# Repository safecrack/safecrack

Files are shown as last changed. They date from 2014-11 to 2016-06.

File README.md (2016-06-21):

## Safecracker

An autodialer device built as part of the [Ruxcon](https://ruxcon.org.au/) 2014 presentation: [Safecracking on a Budget by Luke Jahnke & Jay Davis](http://2014.ruxcon.org.au/assets/2014/slides/rux-safe-cracking.pdf)

### Requirements

#### Hardware:

- 3D printed parts as per the files provided in the folder 3d_parts
- Arduino and compatible stepper motor shield, for this project the [Arduino Mega 2560](https://www.arduino.cc/en/Main/ArduinoBoardMega2560) and [Arduino Motor Shield](https://www.arduino.cc/en/Main/ArduinoMotorShieldR3) were used.
- [Stepper motor](https://littlebirdelectronics.com.au/products/stepper-motor-68-oz-in-400-steps-rev)
- [Hall Effect Sensor](http://www.freetronics.com.au/pages/hall-effect-magnetic-and-proximity-sensor-module-quickstart-guide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) and magnet for detecting if the lock is open. 
- [Mounting Hub](https://www.pololu.com/product/1203) for connecting the lock coupler to the stepper motor
- [Clamping Hub](https://littlebirdelectronics.com.au/products/clamping-hub-6mm-bore) for connecting chassis components.
- [Suction Cups](http://www.ggrglass.co.uk/suction-mounts/7kg-suction-mount-with-1-4-long-stud/) for mounting.

#### Software:

The code uploaded was used for the 2014 presentation but can be modified to be stand alone. It uses a python script to communicate over the usb/serial connection to the arduino to feed it combinations found on twitter. 

### License

See the [LICENSE](LICENSE) file for license rights and limitations.

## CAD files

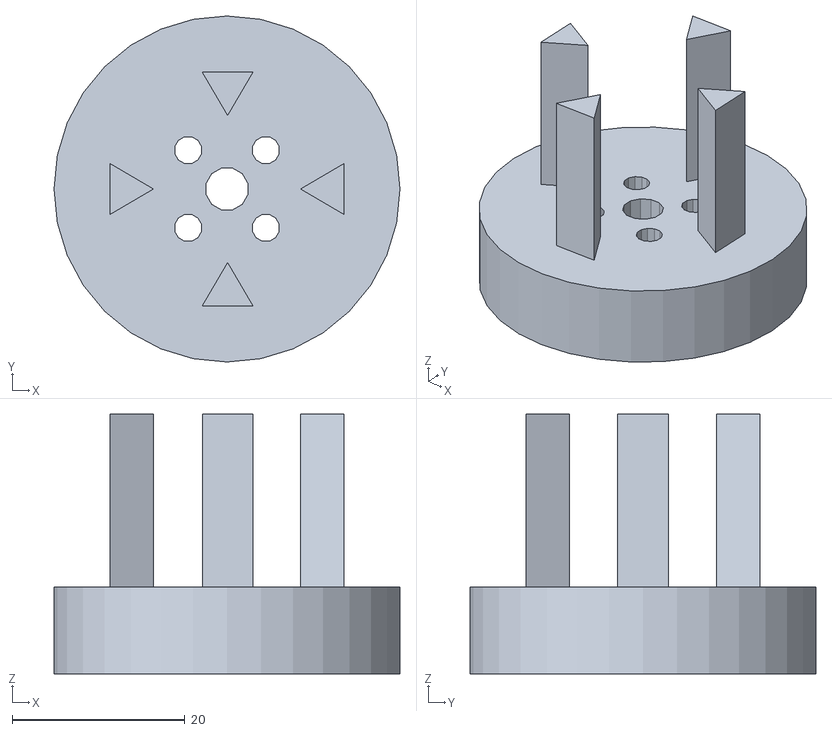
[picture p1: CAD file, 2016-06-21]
3d_parts/stl_files/master_lock_coupler.stl
40.0 x 40.0 x 30.0

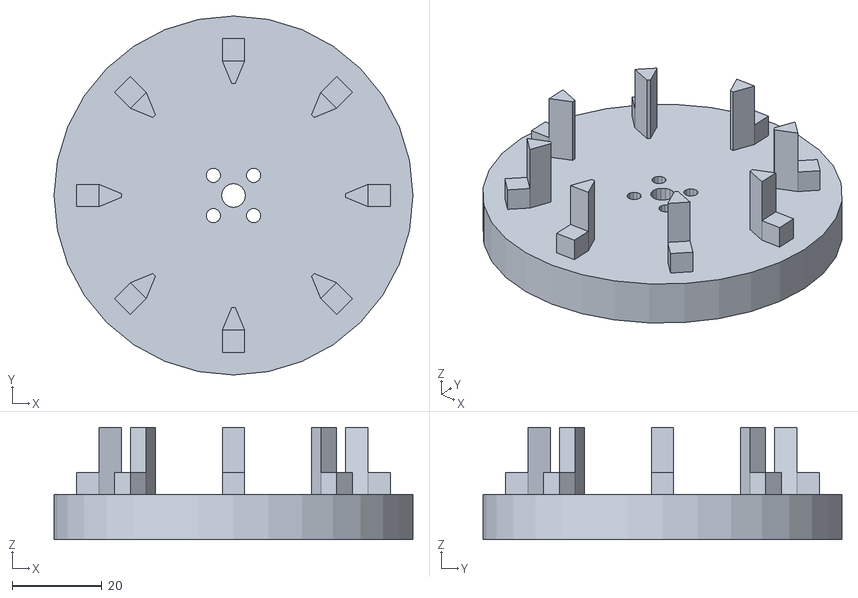
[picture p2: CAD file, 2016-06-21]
3d_parts/stl_files/la_guard_3330_coupler.stl
80.0 x 80.0 x 25.0

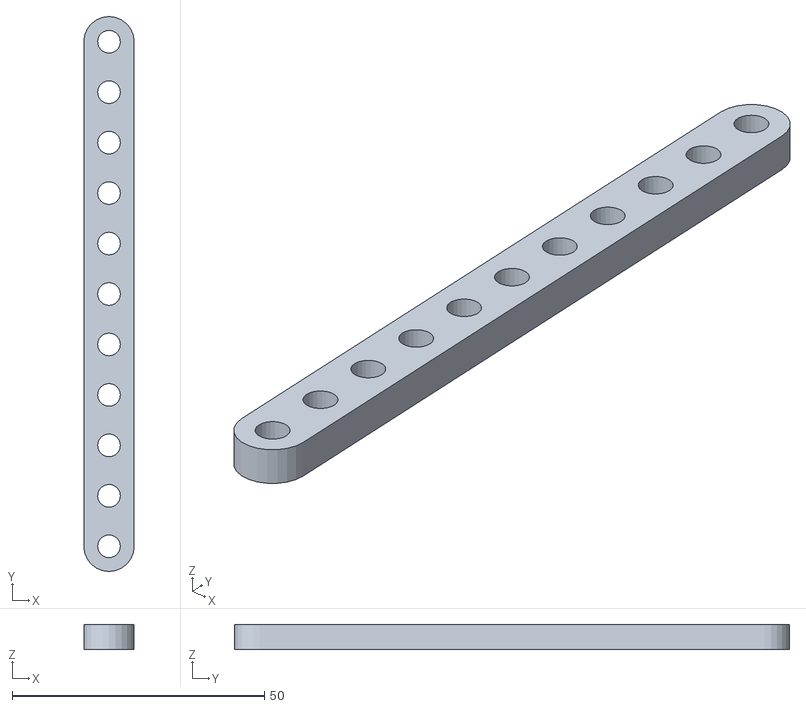
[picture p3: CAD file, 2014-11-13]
3d_parts/stl_files/sensor_arm_2.stl
10.0 x 110.0 x 5.00

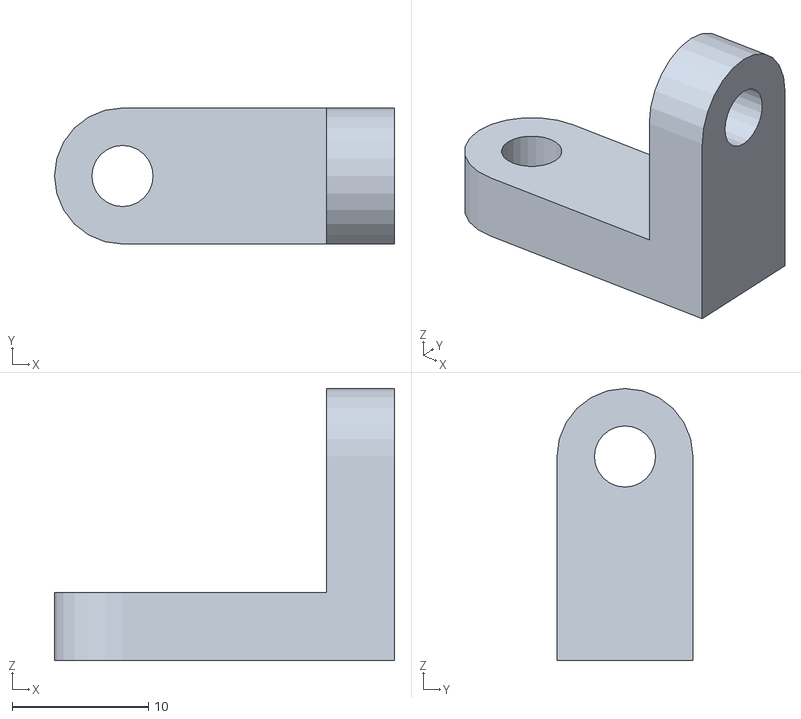
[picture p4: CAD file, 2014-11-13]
3d_parts/stl_files/sensor_arm_3.stl
25.0 x 10.00 x 20.0

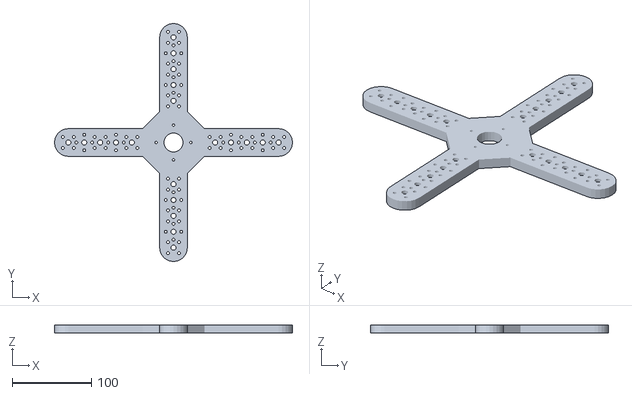
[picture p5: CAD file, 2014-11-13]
3d_parts/stl_files/topmount.stl
300.0 x 300.0 x 10.00

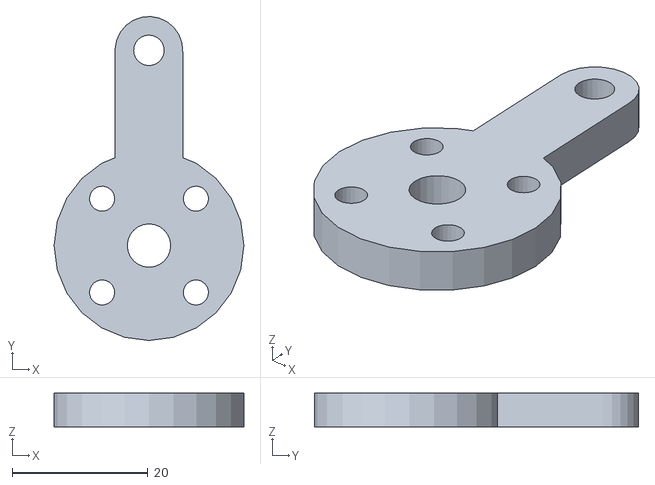
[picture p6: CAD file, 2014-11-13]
3d_parts/stl_files/sensor_arm_1.stl
28.0 x 47.8 x 5.00

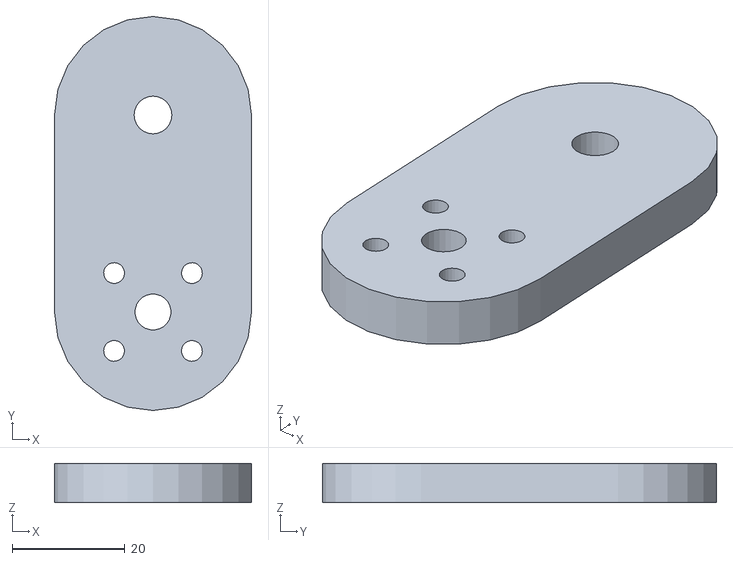
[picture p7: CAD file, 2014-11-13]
3d_parts/stl_files/mounting_arms.stl
35.0 x 70.0 x 7.00

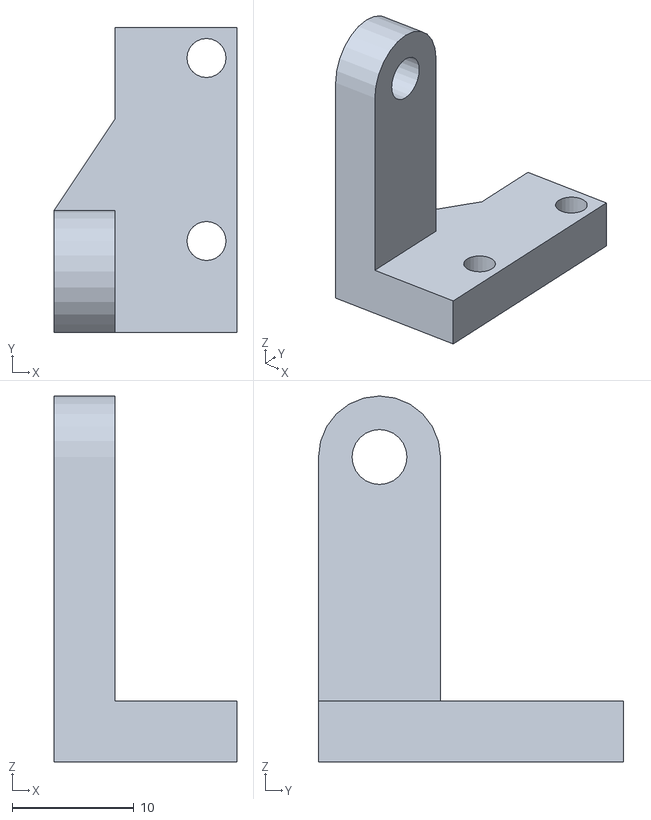
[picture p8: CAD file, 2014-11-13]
3d_parts/stl_files/sensor_mount.stl
15.0 x 25.0 x 30.0

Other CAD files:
3d_parts/sketchup_designs/extra/6mm_clamping_hub.skp
3d_parts/sketchup_designs/extra/Concept.skp
3d_parts/sketchup_designs/extra/nema17stepper.skp
3d_parts/sketchup_designs/mounting_arms.skp
3d_parts/sketchup_designs/sensor_arm_1.skp
3d_parts/sketchup_designs/sensor_arm_2.skp
3d_parts/sketchup_designs/sensor_arm_3.skp
3d_parts/sketchup_designs/sensor_mount.skp
3d_parts/sketchup_designs/topmount.skp

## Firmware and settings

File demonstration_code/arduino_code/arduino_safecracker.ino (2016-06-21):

  #include <AccelStepper.h>


const int PWMA_PIN = 3;
const int PWMB_PIN = 11;
const int BRAKEA_PIN = 9;
const int BRAKEB_PIN = 8;
const int DIRA_PIN = 12;
const int DIRB_PIN = 13;

// these are buttons, oriented with wires at top
const int LEFT_PIN = 26;
const int RIGHT_PIN = 24;
const int CONFIRM_PIN = 22;

const int POSITION_COUNT = 100;
const int STEP_COUNT = 400;
// assert that no remainder or you're going to have a bad time
const int STEPS_PER_POSITION = STEP_COUNT/POSITION_COUNT;

const int HALL_EFFECT_PIN = 44;

const int PIEZO_PIN = 48;

AccelStepper stepper(AccelStepper::FULL2WIRE, DIRA_PIN, DIRB_PIN);

void setup() {
  Serial.begin(115200);
  
  pinMode(PWMA_PIN, OUTPUT);
  pinMode(PWMB_PIN, OUTPUT);
  pinMode(BRAKEA_PIN, OUTPUT);
  pinMode(BRAKEB_PIN, OUTPUT);
  
  pinMode(LEFT_PIN, INPUT);
  pinMode(CONFIRM_PIN, INPUT);
  pinMode(RIGHT_PIN, INPUT);
  
  pinMode(HALL_EFFECT_PIN, INPUT);
  
  digitalWrite(PWMA_PIN, HIGH);
  digitalWrite(PWMB_PIN, HIGH);
  digitalWrite(BRAKEA_PIN, LOW);
  digitalWrite(BRAKEB_PIN, LOW);

  calibrateToZero();
  
  Serial.print("ready\n");
  return;
  /**/
  
  // maybe move to loop?
  boolean result = false;
  
  int increment = 2;
  for(
    long int i=2445; !result && i < 9999; i++
  ) {
    int first = i/100;
    int second = i%100;
    int third;
    for( third = second; result == false && third < POSITION_COUNT ; third += increment ) {
      result = tryCombination(first, second, third);
      // trying one combination
    }
    if( result ) break;
    for( third = 0; result == false && third < second; third += increment ) {
      result = tryCombination(first, second, third);
    }
  }
}

void clockwiseStep(int steps) {
  stepper.move(-steps);
  stepper.runToPosition();
}

void anticlockwiseStep(int steps) {
  clockwiseStep(-steps);
}

void clockwise(int distance) {
  clockwiseStep(STEPS_PER_POSITION * distance);
}

boolean checkCombination() {
  int magnetRead;
  int i;
  /* works! 100/600/600 ~ok too
  stepper.setAcceleration(100);
  stepper.setMaxSpeed(200);
  stepper.setSpeed(200);
  */
  
  clockwise(10);
  stepper.setAcceleration(100);
  stepper.setMaxSpeed(600);
  stepper.setSpeed(600);
  int increment = 3;
  for( i = 0; i < 3; i++ ) {
    magnetRead = !digitalRead(HALL_EFFECT_PIN);
    if( magnetRead == 1 ) {            
      Serial.print("wrong\n");
      break;      
    }
    /* Used this to get feedback - UP TO HERE */
    else if( magnetRead == 0) {
      /*Serial.print(magnetRead);
      digitalWrite(PIEZO_PIN, HIGH);
      delay(5000);
      digitalWrite(PIEZO_PIN, LOW);*/
      Serial.print("nothing\n");
    }
    /**/
    clockwise(increment);
  } 
  
  if( magnetRead == 1 ) {
    stepper.setAcceleration(10000);
    stepper.setMaxSpeed(600);
    stepper.setSpeed(600);
    anticlockwise(10);
    anticlockwise(i*increment);
  }
  /*
  else {
    stepper.setAcceleration(100);
    stepper.setMaxSpeed(200);
    stepper.setSpeed(200);
    for( ; i > 0; i-- ) {
      magnetRead = !digitalRead(HALL_EFFECT_PIN);
      if( magnetRead == 1 ) {
        break;
      }
      anticlockwise(3);
    }
  }
  */  
  return !magnetRead;
}

void anticlockwise(int distance) {
  clockwise(-distance);
}
int prevFirst = -1, prevSecond = -1, prevThird = -1;
boolean tryCombination(int first, int second, int third) {
  
  //Serial.print("Trying: ");
  //Serial.print(first);
  //Serial.print(",");
  //Serial.print(second);
  //Serial.print(",");
  //Serial.print(third);
  //Serial.print("\n");
  
  // order has **SWAPPED**, this is speed/speed/accel
  // 200 200 100
  // fast: 600 600 c (500/500 == bad too)
  
  //* FAST! 10k,600,600
  stepper.setAcceleration(10000);
  stepper.setMaxSpeed(700);
  stepper.setSpeed(700);
  /**/
  
  /* SLOW
  stepper.setAcceleration(100);
  stepper.setMaxSpeed(200);
  stepper.setSpeed(200);
  /**/
  
  if( //false &&
prevFirst == first && prevSecond == second && ( ( third > second && third > prevThird ) || ( third < second && ( (prevThird >= second) || (prevThird < second && third > prevThird) ) ) )
  ) {
    //Serial.print("shortcut baby!\n");
    // we must be at 0
    
    anticlockwise(third);
    
    if( third < second ) {
      anticlockwise(POSITION_COUNT);
      clockwise(POSITION_COUNT);
    }
    
    // change direction and go to zero
    //clockwise((POSITION_COUNT+(third-0))%POSITION_COUNT);
    clockwise(third);
    
    prevFirst = first;
    prevSecond = second;
    prevThird = third;
    return checkCombination();
    //return (third>29 && second == 20);
  }
  
  
  // rotate 3 times to reset
  anticlockwise(3 * POSITION_COUNT);
  
  // continue to first number
  // assumption here that numbers increase when rotating anticlockwise (opposite of clock hands)
  anticlockwise(first);
  
  // change direction and move to the second number
  // we add POSITION_COUNT to prevent negative numbers (which are possible because C)
  clockwise((POSITION_COUNT+(first-second))%POSITION_COUNT);
  
  // continue and rotate twice
  clockwise(2 * POSITION_COUNT);
  
  // change direction and move to the third number
  anticlockwise((POSITION_COUNT+(third-second))%POSITION_COUNT);

  // continue and rotate once
  anticlockwise(1 * POSITION_COUNT);
  
  // change direction and go to zero
  clockwise((POSITION_COUNT+(third-0))%POSITION_COUNT);
  //stepper.move(4 * first);
  //stepper.runToPosition();
  
  
  /* all together..
  anticlockwise((3 * POSITION_COUNT)+first);
  clockwise(((POSITION_COUNT+(first-second))%POSITION_COUNT)+(2 * POSITION_COUNT));
  anticlockwise(((POSITION_COUNT+(third-second))%POSITION_COUNT)+(1 * POSITION_COUNT));
  clockwise((POSITION_COUNT+(third-0))%POSITION_COUNT);
  /* end big dirty hack */
  
  /* for optimisation */
  prevFirst = first;
  prevSecond = second;
  prevThird = third;
  /**/
  
  return checkCombination();
}

// the only side effect of calling this is current position = 0
void calibrateToZero() {
  // consider where these should be and whether they should be undone before return
  stepper.setMaxSpeed(200);
  stepper.setSpeed(10);
  stepper.setAcceleration(10);
  
  for( ;; ) {
    if( digitalRead(CONFIRM_PIN) == HIGH ) {
      // TODO - should this be done here?
      stepper.setCurrentPosition(0);
      return;
    }
    
    if( digitalRead(LEFT_PIN) == HIGH ) {
      clockwiseStep(1);
    }
    else if( digitalRead(RIGHT_PIN) == HIGH ) {
      anticlockwiseStep(1);
    }
    else {
      //stepper.stop();
    }
  }
}

void loop() {
  //Serial.print(".\n");
  // if there's any serial available, read it:
  while (Serial.available() > 0) {

    // look for the next valid integer in the incoming serial stream:
    int first = Serial.parseInt();
    // do it again:
    int second = Serial.parseInt();
    // do it again:
    int third = Serial.parseInt();

    // look for the newline. That's the end of your
    // sentence:
    if (Serial.read() == '\n' && first < 100 && second < 100 & third < 100 && first >= 0 && second >= 0 && third >= 0) {
      // print the three numbers in one string as hexadecimal:
      //Serial.print(red, HEX);
      //Serial.print(green, HEX);
      //Serial.println(blue, HEX);
      tryCombination(first,second,third);
      Serial.print("ready\n");
    }
  }
}

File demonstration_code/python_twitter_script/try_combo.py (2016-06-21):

#!/usr/bin/env python

import sys
import serial
import re
import twitter_birdy

new_tweet_list = []
old_tweet_list = []
try_tweet = []
found = 0

print "Connecting to arduino..."
ser = serial.Serial('/dev/ttyACM3', 115200)
print "Connected!"


while found == 0:
  print "---------------------------------"
  print "Waiting for arduino"
  ser_line = ser.readline()
  sys.stdout.write("arduino:" + ser_line)
  if ser_line != "ready\n":
    continue
  print "Waiting for combination..."

  try_tweet, new_tweet_list, old_tweet_list = twitter_birdy.gimme_tweet(old_tweet_list, new_tweet_list)
  for combo in try_tweet:
    combo = combo + "\n"
    if not combo:
      print "End found, exiting loop"
      break
    regex = re.compile('^[0-9]{2} [0-9]{2} [0-9]{2}$')
    if regex.match(combo):
      print "Combo %s is good, going to send to arduino" % combo.rstrip()
      ser.write(combo)
      i = 0
      while i <= 2:
          i += 1
          result = ser.readline()
          if result == "wrong\n":
              break
      if result == "ready\n":
          print "Your counting is wrong"
      elif result == "nothing\n":
          print "Found Combo!...Stopping"
          found = 1
          break
      elif result == "wrong\n":
          print "Hall effect triggered, moving on"
      print "---------------------------------"
    else:
      print "Invalid combination received:"

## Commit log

2014-11-13 3D Designs
    [6mm_clamping_hub.skp, Concept.skp, mounting_arms.skp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]
2016-06-21 Added Twitter demo code, Arduino code, and coupler STL's, modified README.md and LICENSE
    [la_guard_3330_coupler.stl, master_lock_coupler.stl]
